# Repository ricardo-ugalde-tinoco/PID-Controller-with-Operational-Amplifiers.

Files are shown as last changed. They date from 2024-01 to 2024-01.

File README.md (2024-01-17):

Design of a PID controller using different arrays of operational amplifiers in order to be able to regulate the temperature of a freezer.
For this application an LM35 sensor was used, because it is a sensor that does not require to be connected to a microprocessor to perform the temperature measurement and delivers an analogue output signal.

In addition, LM741 operational amplifiers were used, these general purpose operational amplifiers have a high performance in temperatures from -55° C to 125° C, another reason why this model was used was the fact that it has a protection against overloads at the input and output of each power supply pin.

Finally, a power stage was used to amplify the current in order to supply an actuator capable of temperature correction. However, the actuator was not included because the main focus is on the development of the controller.
In this power stage, BC337 (NPN) and BC327 (PNP) bipolar transistors were used, as they are a common model in small motor driver applications.

If you wish to consult the calculations, a PDF document with all the calculations will be attached.

To check the correct operation of the circuit, simulations were carried out in LTSpice. As the one shown below where I try to obtain a gain of 10 at a voltage of 0.5 Volts.



In the project scheme I wrote down all the formulas needed to find the value of each of the resistors and components used in the conventional notation of the diagrams.
As shown in the following image.



This practice is very useful to describe more precisely your connections and the sequence to develop your circuit.

Model of the completed PCB.



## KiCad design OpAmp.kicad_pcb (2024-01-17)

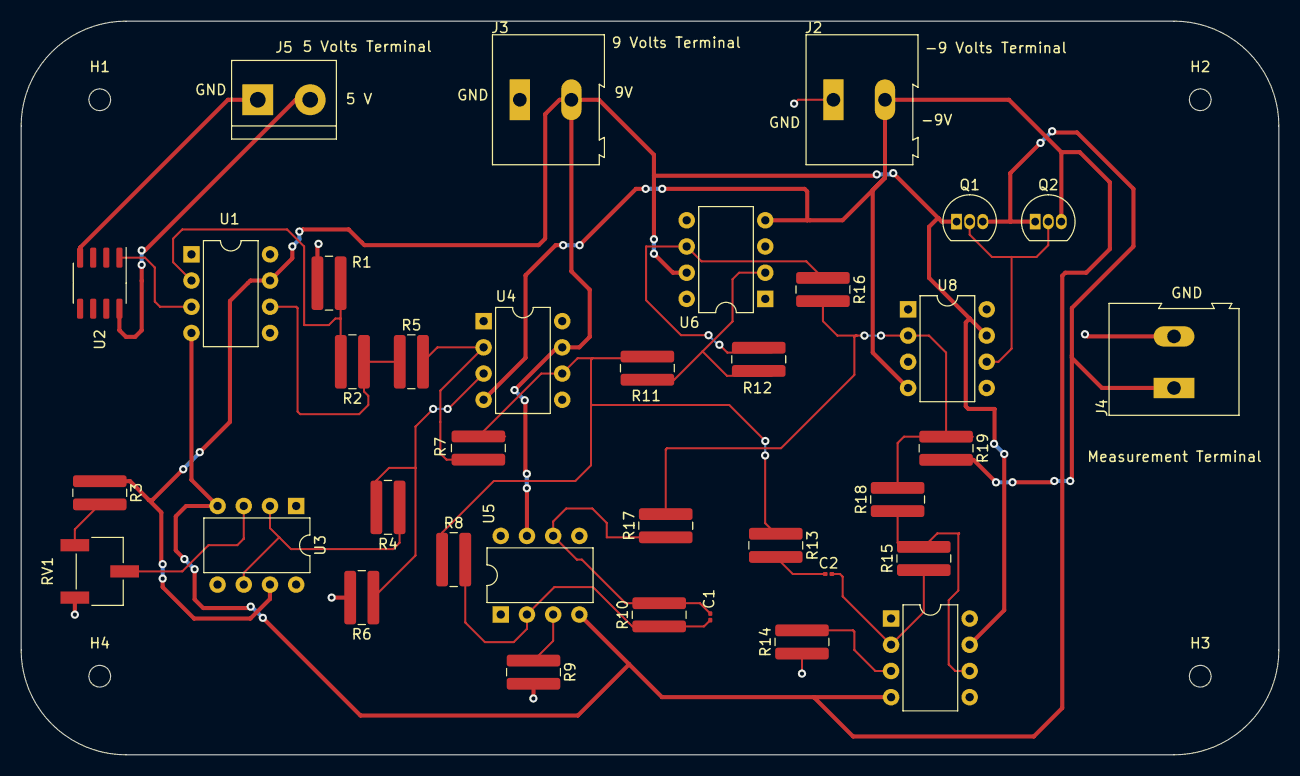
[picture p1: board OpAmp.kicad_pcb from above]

Board: 2 copper layers, 121.9 x 71.1 mm, 40 parts (0 on the bottom side), 25 nets.

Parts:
C1: 100u; C_0201_0603Metric
C2: 0.1u; C_0201_0603Metric
H1, H2, H3, H4: MountingHole; MountingHole_2.1mm
J2, J3, J4: Screw_Terminal_01x02; TerminalBlock_Altech_AK300-2_P5.00mm
J5: Screw_Terminal_01x02; TerminalBlock_bornier-2_P5.08mm
Q1: BC337; TO-92_Inline
Q2: BC327; TO-92_Inline
R1: 1K; R_1020_2550Metric
R2: 9K; R_1020_2550Metric
R3: 160; R_1020_2550Metric
R4, R5, R6, R7, R16, R17, R18, R19: 1k; R_1020_2550Metric
R8: 289.35; R_1020_2550Metric
R9: 263.23; R_1020_2550Metric
R10: 3674.745; R_1020_2550Metric
R11: 20; R_1020_2550Metric
R12: 4338.2; R_1020_2550Metric
R13: 125; R_1020_2550Metric
R14, R15: 1592.5; R_1020_2550Metric
RV1: 200; Potentiometer_Bourns_3269W_Vertical
U1, U3, U4, U5, U6, U7, U8: LM741; DIP-8_W7.62mm
U2: LM35-D; SOIC-8_3.9x4.9mm_P1.27mm

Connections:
+5V: J5.2, U2.8 (+V_{S})
+9V: J3.2, Q1.1 (C), R3.1, U1.7 (V+), U3.7 (V+), U4.7 (V+), U5.7 (V+), U6.7 (V+), U7.7 (V+), U8.7 (V+)
-9V: J2.2, Q2.3 (E), U1.4 (V-), U3.4 (V-), U4.4 (V-), U5.4 (V-), U6.4 (V-), U7.4 (V-), U8.4 (V-)
GND: J2.1, J3.1, J4.2, J5.1, R1.2, R6.2, R9.2, R14.1, RV1.3, U2.4 (GND), U6.3 (+), U8.3 (+)
unnamed: C1.2, R10.2, R17.1, U5.6
unnamed: C2.1, R13.2
unnamed: J4.1, Q1.3 (E), Q2.1 (C), R19.2
unnamed: Q1.2 (B), Q2.2 (B), U8.6
unnamed: R2.1, R5.1, U1.6
unnamed: R3.2, RV1.1
unnamed: R7.2, R8.1, R11.2, R13.1, U4.6
unnamed: R12.2, R16.1, U6.6
unnamed: R15.2, R18.1, U7.6
unnamed: U1.3 (+), U2.1 (V_{OUT})
unnamed: R1.1, R2.2, U1.2 (-)
unnamed: RV1.2, U3.3 (+)
unnamed: R4.1, U3.2 (-), U3.6
unnamed: R4.2, R6.1, U4.3 (+)
unnamed: R5.2, R7.1, U4.2 (-)
unnamed: R9.1, U5.3 (+)
unnamed: C1.1, R8.2, R10.1, U5.2 (-)
unnamed: R11.1, R12.1, U6.2 (-)
unnamed: R14.2, U7.3 (+)
unnamed: C2.2, R15.1, U7.2 (-)
unnamed: R16.2, R17.2, R18.2, R19.1, U8.2 (-)
